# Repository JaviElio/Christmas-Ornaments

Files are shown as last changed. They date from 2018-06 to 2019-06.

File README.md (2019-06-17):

View this project on [CADLAB.io](https://cadlab.io/project/1880). 

# Christmas-Ornaments
ESP8266 Christmas ornaments 

Based on this project:

	- Title:	ESP8266 Christmas Ornaments!
	- Author:	Sean Hodgins
	- Link:		https://www.instructables.com/id/ESP8266-Christmas-Ornaments/

FEATURES:

If front button of the ornament is pressed, a random song is played. Then, other ornaments plays a song too (within 5 min max.)

Every time the front button is pressed a counter in thinkSpesk.com is increased. Also, every 5 min. the counter is checked to know if a song must be played.

If the ornament could not reach a wifi AP, a captative portal is activated to configure a connection to different Wifi AP.

PICTURES:

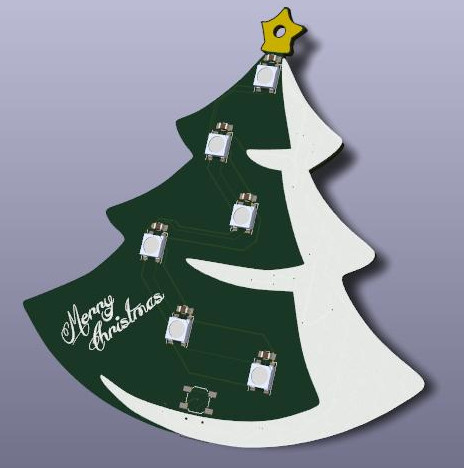
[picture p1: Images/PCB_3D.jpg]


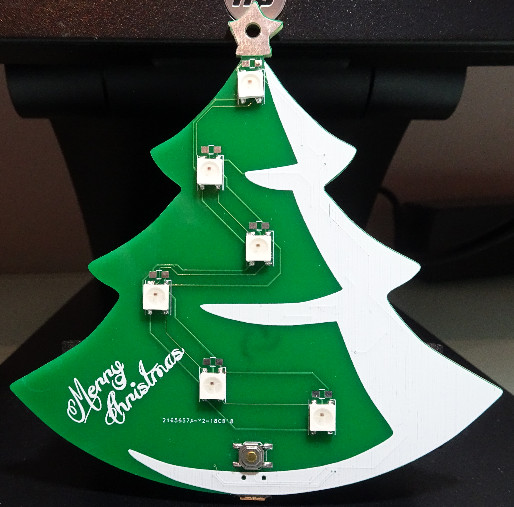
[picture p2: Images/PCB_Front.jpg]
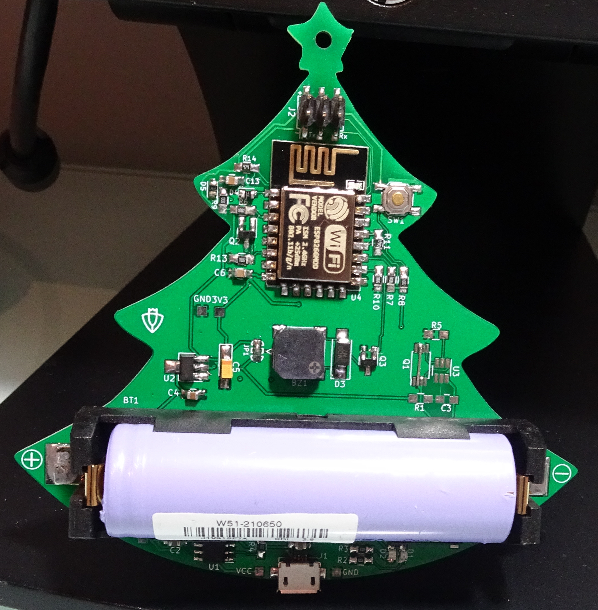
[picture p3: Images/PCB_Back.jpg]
		

TO IMPROVE:

Voltage regulator doesn't work if battery protection circuit is populated.

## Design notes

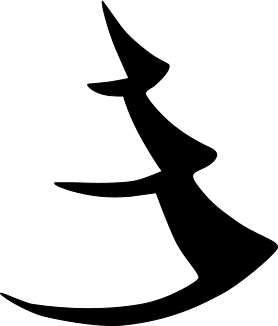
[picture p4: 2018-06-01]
Images/Tree_Shadow.png

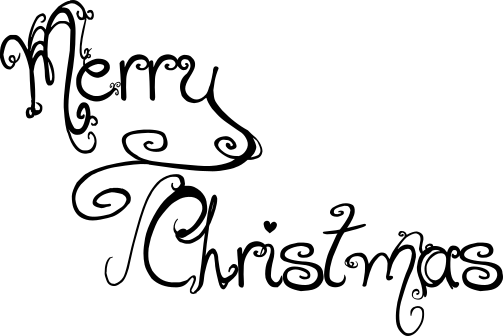
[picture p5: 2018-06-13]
Images/Text2.png

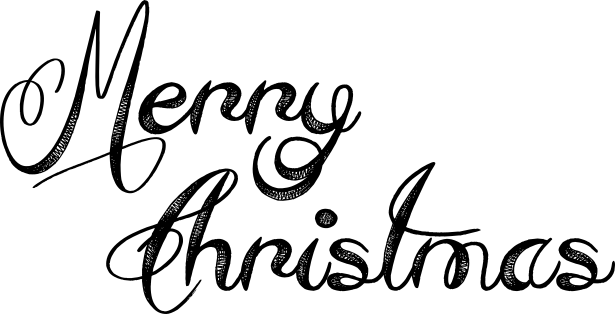
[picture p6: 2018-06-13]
Images/Text.png

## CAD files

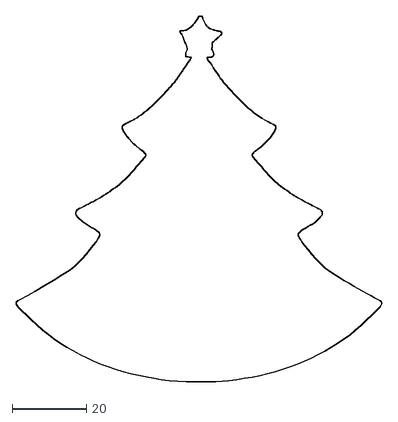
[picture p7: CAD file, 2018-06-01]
Images/Tree.dxf
98.8 x 98.7

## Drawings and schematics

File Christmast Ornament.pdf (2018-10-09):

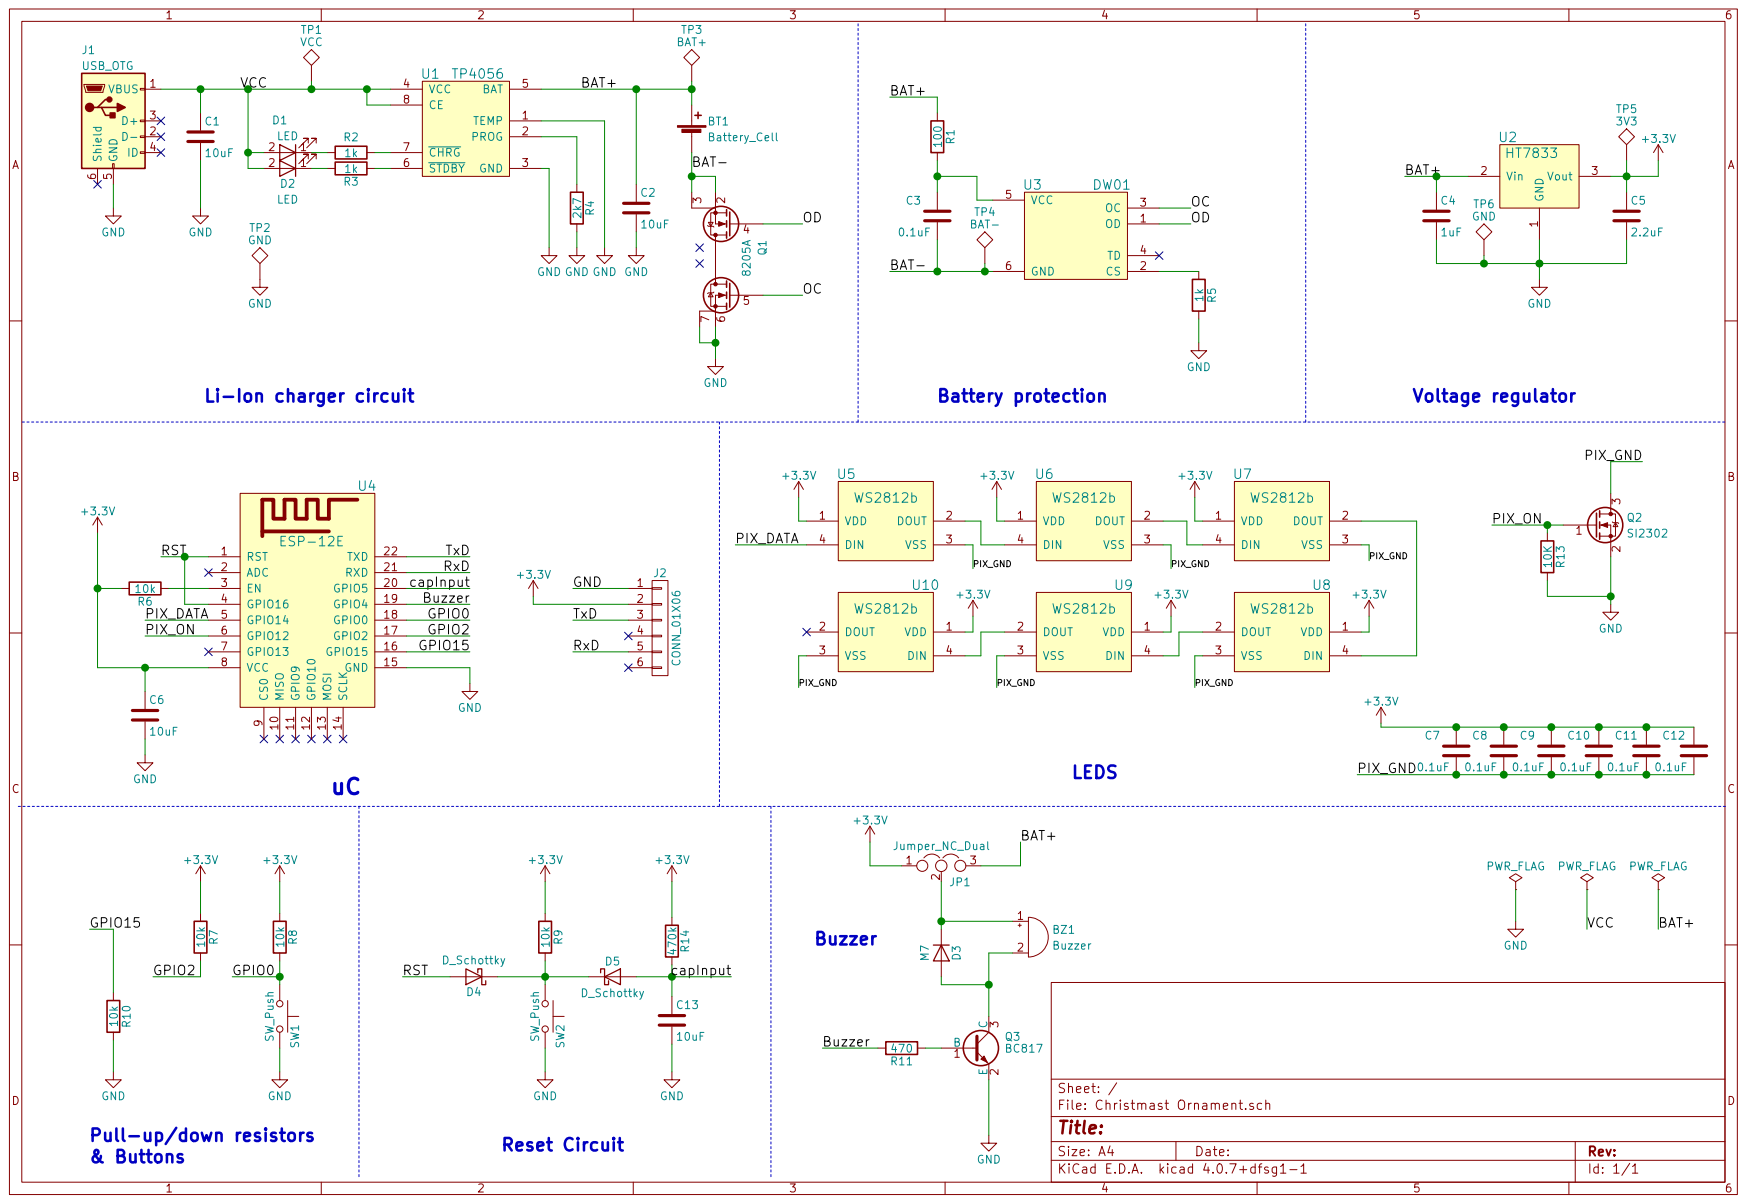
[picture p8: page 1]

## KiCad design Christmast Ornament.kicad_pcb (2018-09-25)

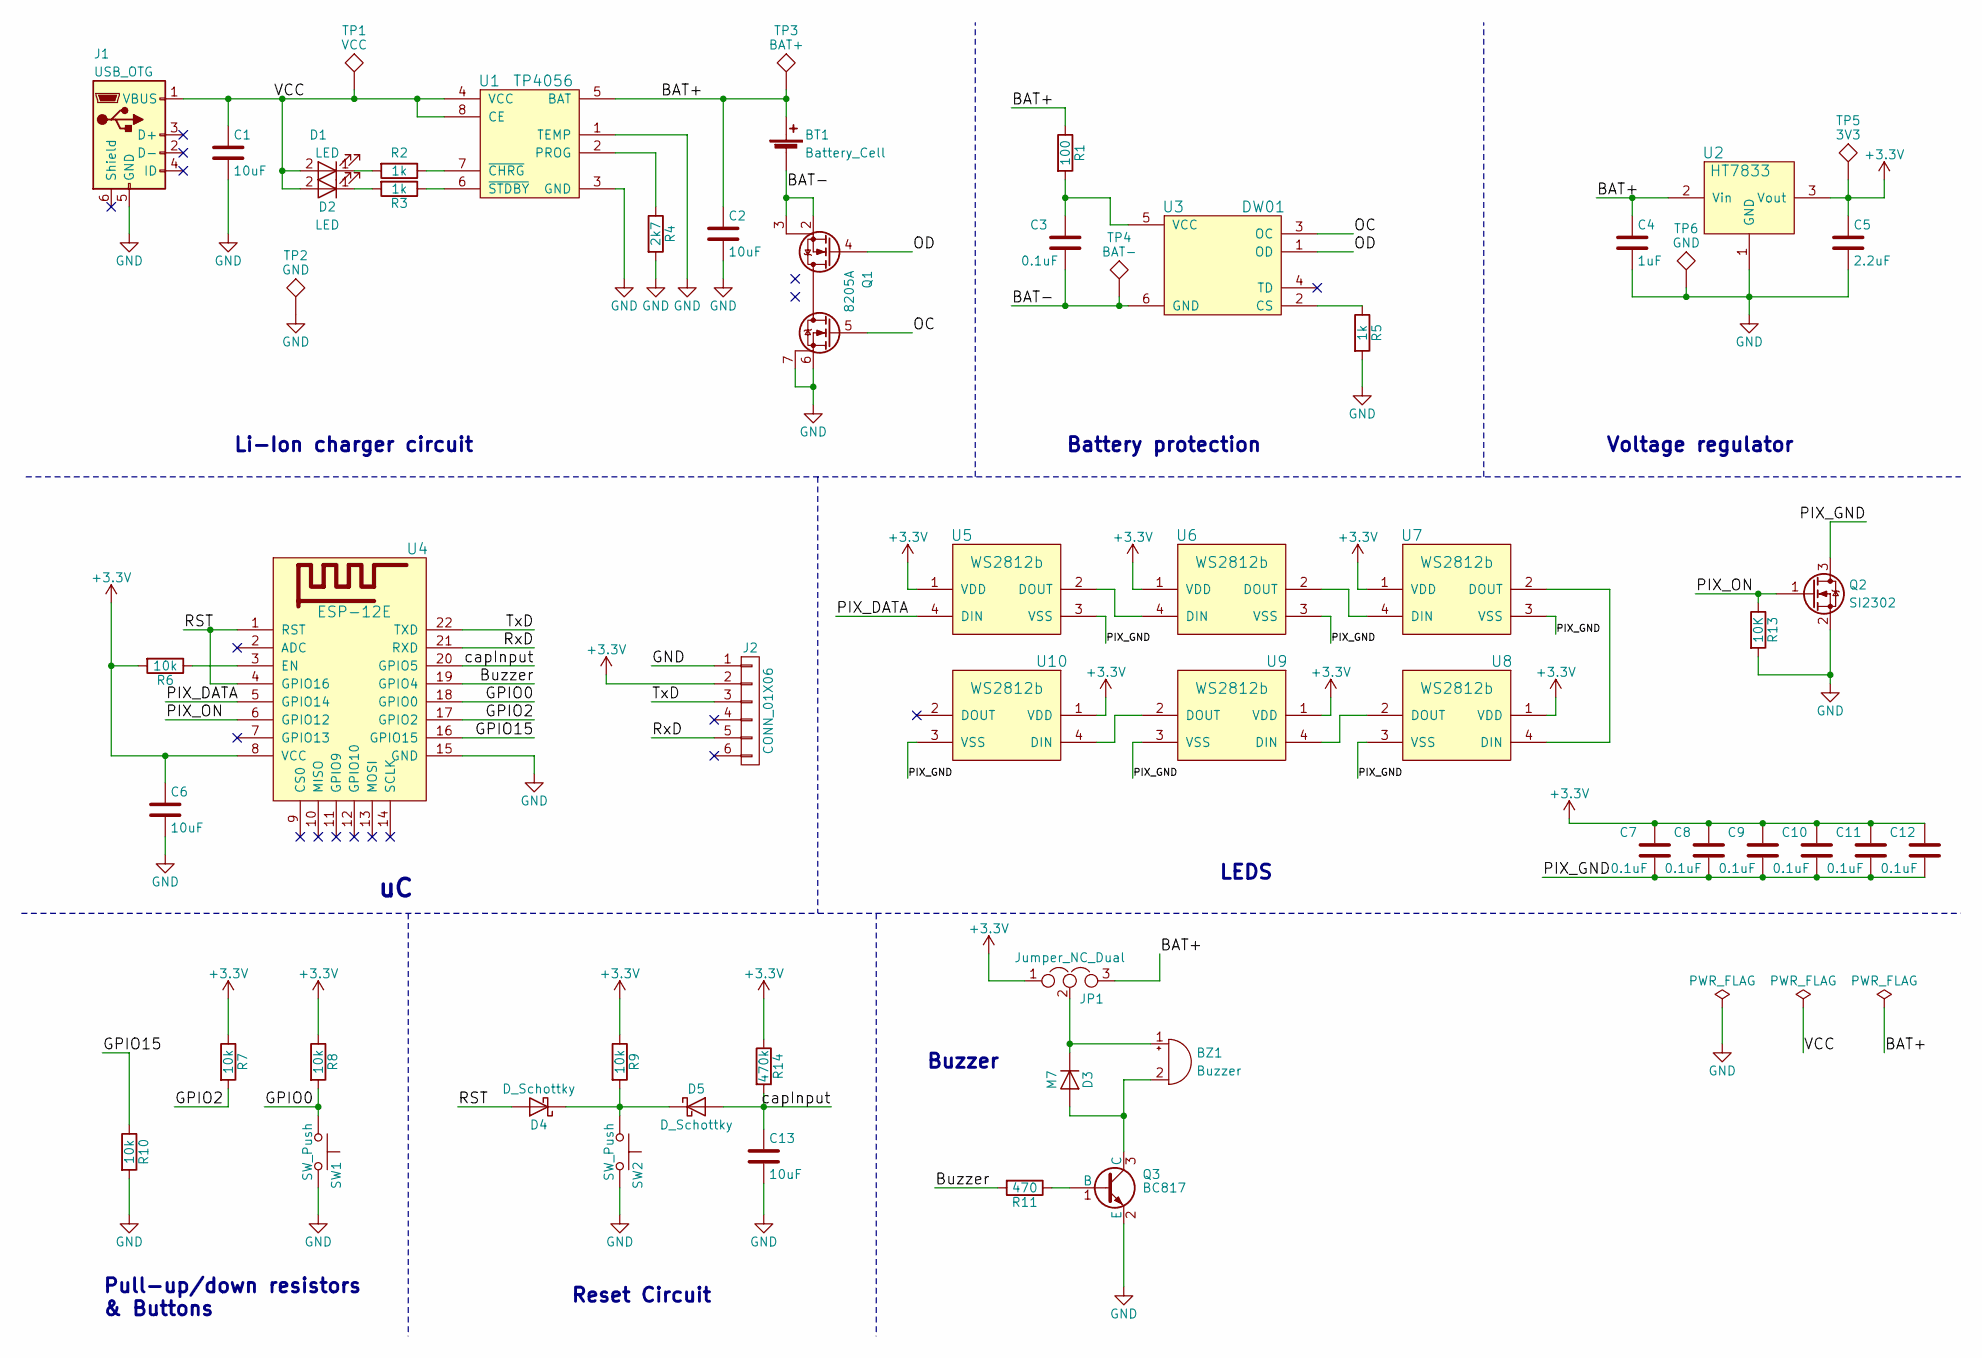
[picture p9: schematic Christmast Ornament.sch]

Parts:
BT1: Battery_Cell; 18650_SMD_Case
BZ1: Buzzer; Buzzer_8.5x8.5mm
C1, C2, C6, C13: 10uF; C_0805_HandSoldering
C3, C7, C8, C9, C10, C11, C12: 0.1uF; C_0805_HandSoldering
C4: 1uF; C_0805_HandSoldering
C5: 2.2uF; CP_Tantalum_Case-A_EIA-3216-18_Hand
D1, D2: LED; LED_0805
D3: M7; D_SMA_Handsoldering
D4, D5: D_Schottky; D_0805
J1: USB_OTG; MicroUSB
J2: CONN_01X06; Pin_Header_Straight_2x03_Pitch2.54mm_SMD
JP1: Jumper_NC_Dual; Jumper_2-NC
Q1: 8205A; TSSOP-8_4.4x3mm_Pitch0.65mm
Q2: SI2302; SOT-23_Handsoldering
Q3: BC817; SOT-23_Handsoldering
R1: 100; R_0805_HandSoldering
R2, R3, R5: 1k; R_0805_HandSoldering
R4: 2k7; R_0805_HandSoldering
R6, R7, R8, R9, R10: 10k; R_0805_HandSoldering
R11: 470; R_0805_HandSoldering
R13: 10K; R_0805_HandSoldering
R14: 470k; R_0805_HandSoldering
SW1, SW2: SW_Push; SW_SPST_SKQG
TP1: VCC; Measurement_Point_Square-SMD-Pad_Small
TP2, TP6: GND; Measurement_Point_Square-SMD-Pad_Small
TP3: BAT+; Measurement_Point_Square-SMD-Pad_Small
TP4: BAT-; Measurement_Point_Square-SMD-Pad_Small
TP5: 3V3; Measurement_Point_Square-SMD-Pad_Small
U1: TP4056; SOIC-8_3.9x4.9mm_Pitch1.27mm
U2: HT7833; SOT89-3_Housing_Handsoldering
U3: DW01; SOT-23-6_Handsoldering
U4: ESP-12E; ESP-12E_SMD
U5, U6, U7, U8, U9, U10: WS2812b; LED_WS2812B-PLCC4

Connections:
+3V3: C5.1, C6.1, C7.1, C8.1, C9.1, C10.1, C11.1, C12.1, J2.2, JP1.1, R6.2, R7.1, R8.1, R9.1, R14.1, TP5.1, U2.3 (Vout), U4.8 (VCC), U5.1 (VDD), U6.1 (VDD), U7.1 (VDD), U8.1 (VDD), U9.1 (VDD), U10.1 (VDD)
/BAT+: BT1.1 (+), C2.1, C4.1, JP1.3, R1.1, TP3.1, U1.5 (BAT), U2.2 (Vin)
/BAT-: BT1.2 (-), C3.2, Q1.2 (S1), Q1.3 (S1), TP4.1, U3.6 (GND)
/Buzzer: R11.2, U4.19 (GPIO4)
/GPIO0: R8.2, SW1.1, U4.18 (GPIO0)
/GPIO2: R7.2, U4.17 (GPIO2)
/GPIO15: R10.1, U4.16 (GPIO15)
/OC: Q1.5 (G2), U3.3 (OC)
/OD: Q1.4 (G1), U3.1 (OD)
/PIX_DATA: U4.5 (GPIO14), U5.4 (DIN)
/PIX_GND: C7.2, C8.2, C9.2, C10.2, C11.2, C12.2, Q2.3 (D), U5.3 (VSS), U6.3 (VSS), U7.3 (VSS), U8.3 (VSS), U9.3 (VSS), U10.3 (VSS)
/PIX_ON: Q2.1 (G), R13.1, U4.6 (GPIO12)
/RST: D4.2 (A), U4.1 (RST), U4.4 (GPIO16)
/RxD: J2.5, U4.21 (RXD)
/TxD: J2.3, U4.22 (TXD)
/VCC: C1.1, D1.2 (A), D2.2 (A), J1.1 (VBUS), TP1.1, U1.4 (VCC), U1.8 (CE)
/capInput: C13.1, D5.2 (A), R14.2, U4.20 (GPIO5)
GND: C1.2, C2.2, C4.2, C5.2, C6.2, C13.2, J1.5 (GND), J2.1, Q1.6 (S2), Q1.7 (S2), Q2.2 (S), Q3.2 (E), R4.2, R5.2, R10.2, R13.2, SW1.2, SW2.2, TP2.1, TP6.1, U1.1 (TEMP), U1.3 (GND), U2.1 (GND), U4.15 (GND)
unnamed: BZ1.1 (-), D3.1 (K), JP1.2
unnamed: BZ1.2 (+), D3.2 (A), Q3.3 (C)
unnamed: C3.1, R1.2, U3.5 (VCC)
unnamed: D1.1 (K), R2.2
unnamed: D2.1 (K), R3.2
unnamed: D4.1 (K), D5.1 (K), R9.2, SW2.1
unnamed: Q3.1 (B), R11.1
unnamed: R2.1, U1.7 (~CHRG)
unnamed: R3.1, U1.6 (~STDBY)
unnamed: R4.1, U1.2 (PROG)
unnamed: R5.1, U3.2 (CS)
unnamed: R6.1, U4.3 (EN)
unnamed: U5.2 (DOUT), U6.4 (DIN)
unnamed: U6.2 (DOUT), U7.4 (DIN)
unnamed: U7.2 (DOUT), U8.4 (DIN)
unnamed: U8.2 (DOUT), U9.4 (DIN)
unnamed: U9.2 (DOUT), U10.4 (DIN)

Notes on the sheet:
Li-Ion charger circuit
Battery protection
Voltage regulator
LEDS
Buzzer
Pull-up/down resistors & Buttons
Reset Circuit

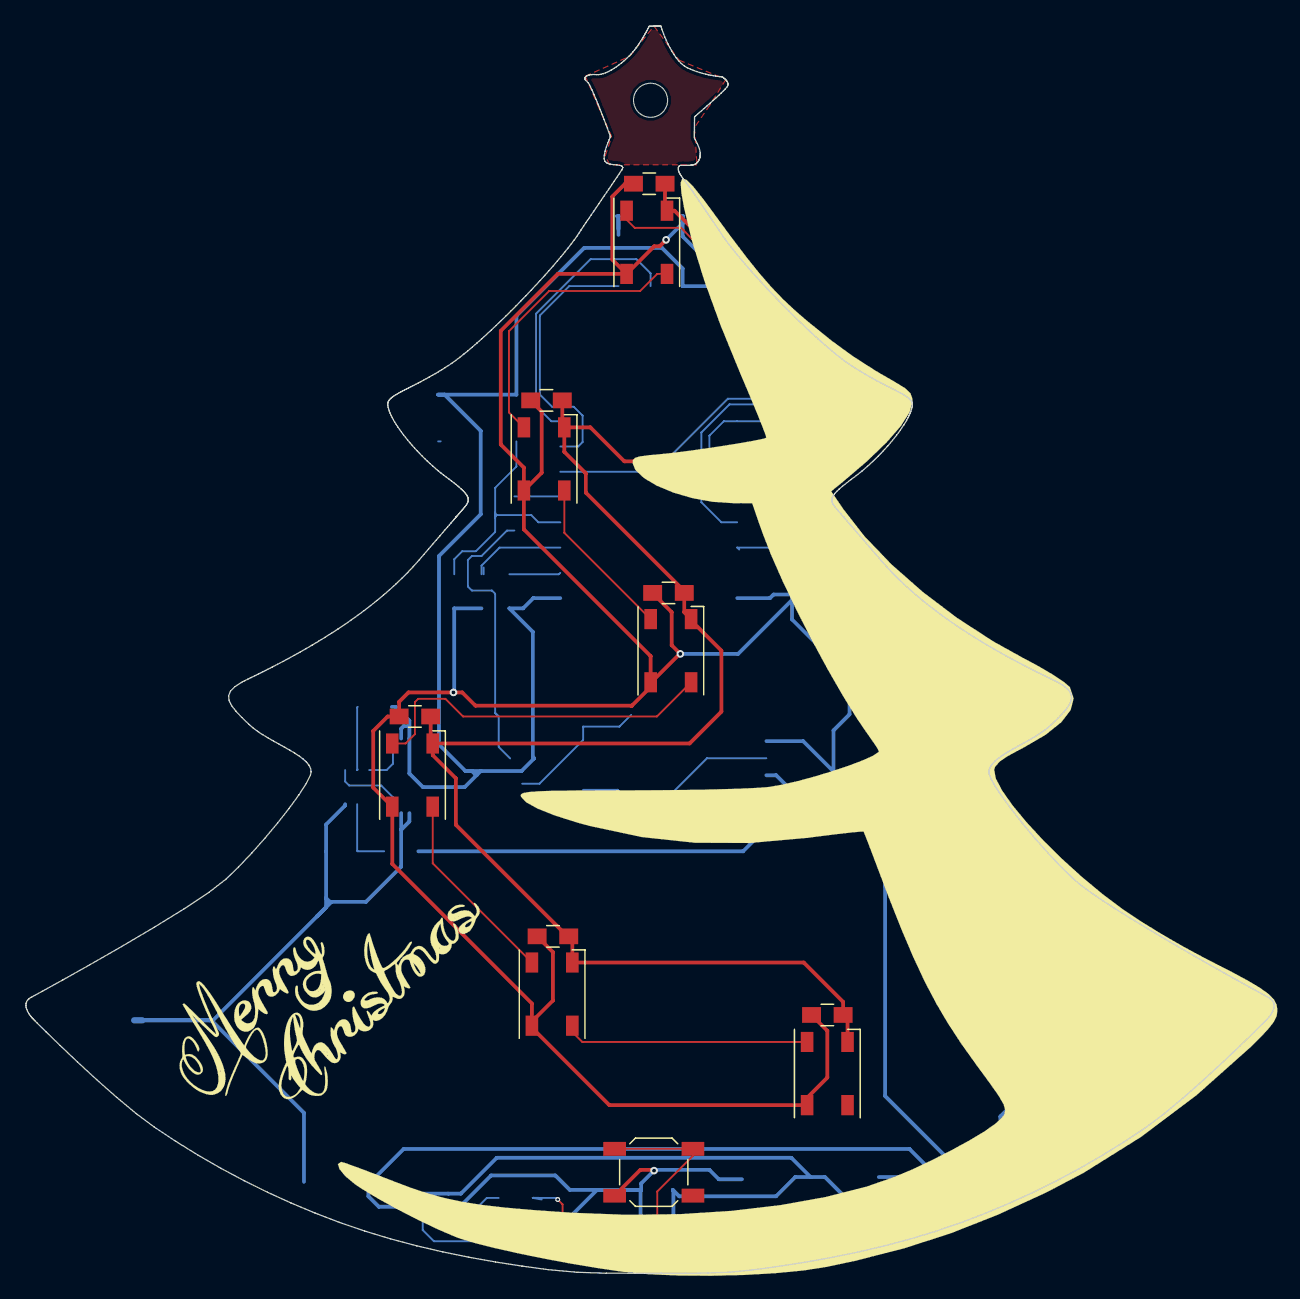
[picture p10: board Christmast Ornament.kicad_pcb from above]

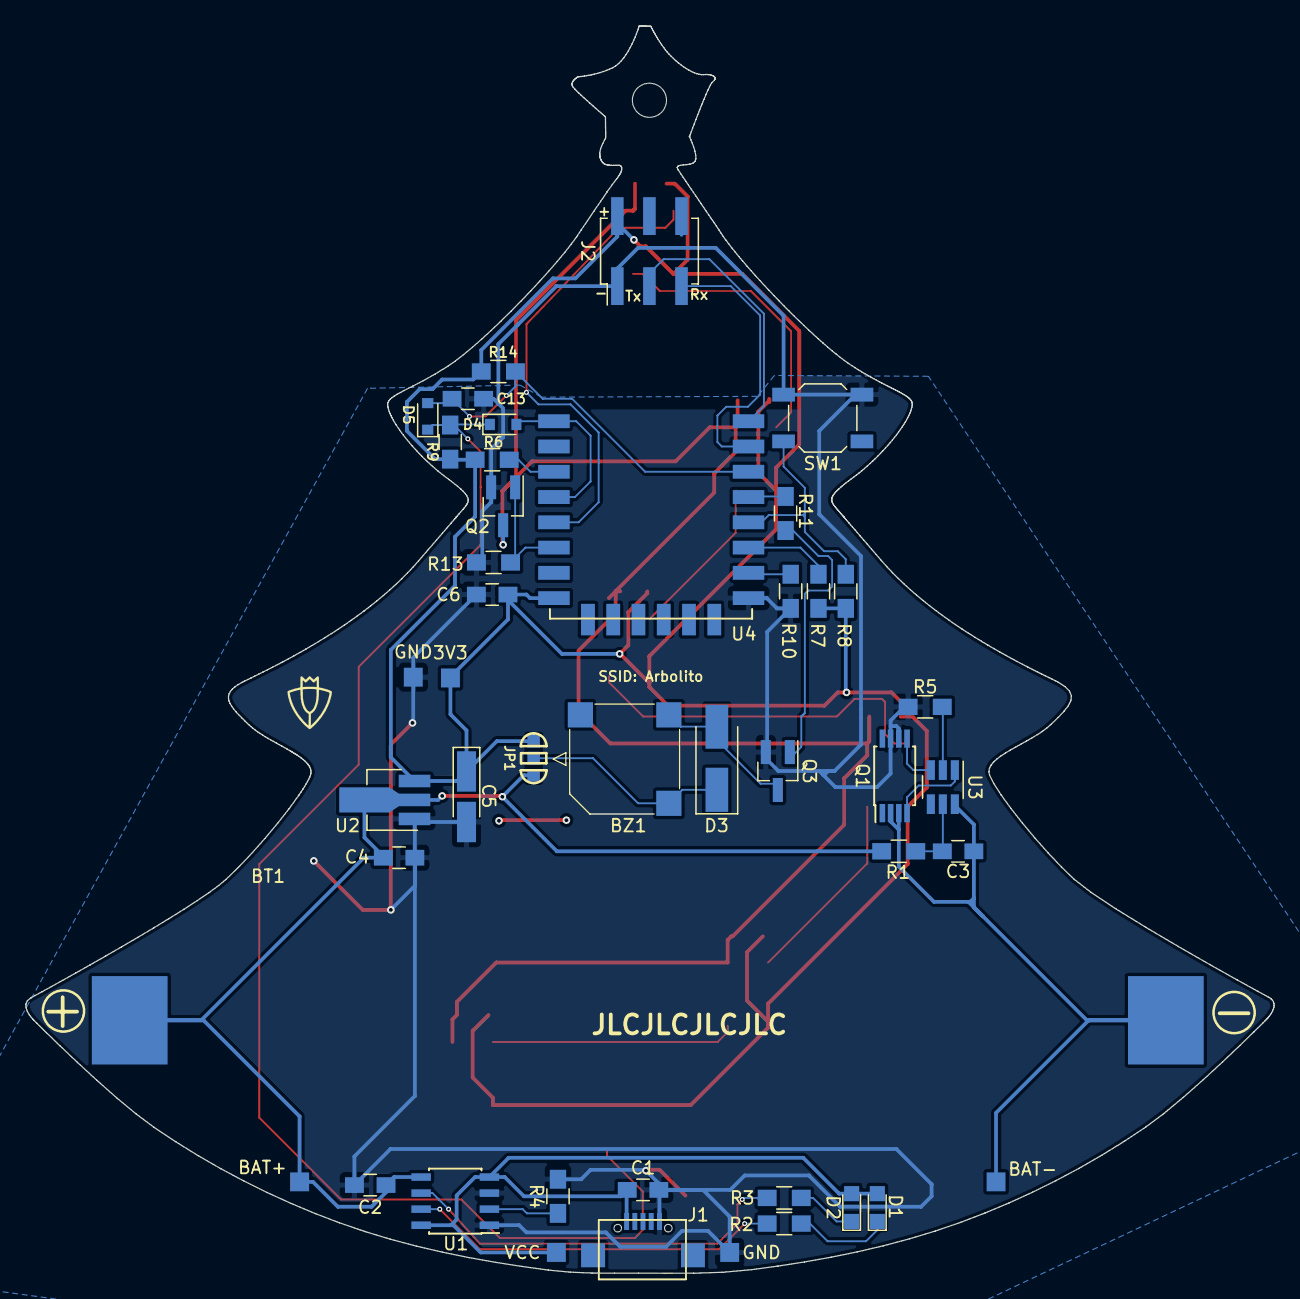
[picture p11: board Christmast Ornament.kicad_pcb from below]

Board: 2 copper layers, 98.8 x 98.7 mm, 57 parts (44 on the bottom side), 35 nets.

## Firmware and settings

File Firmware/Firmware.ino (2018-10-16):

#include <Adafruit_NeoPixel.h>
#include <ESP8266WiFi.h>
#include <DNSServer.h>
#include <ESP8266WebServer.h>
#include <WiFiManager.h>
#include <ThingSpeak.h>
#include <EEPROM.h>
#include <Ticker.h>


#define B3 2024
#define C4 1915
#define D4 1700
#define E4 1519
#define F4 1432
#define FS4 1352
#define G4 1275
#define GS4 415
#define A4 1136
#define AS4 1073
#define B4 1014
#define C5 956
#define D5 852

#define PIXELNUM 6
#define PIXELPIN 14
#define PIXELON  12
#define TONEPIN  4
#define CAPINPUT 5

#define SLEEPMINUTES 5


int song = 1;
bool mute = 0;
int rstReason;
bool capInputState = true;
unsigned long contadorChannel = 399088;
const char* writeContadorKey = "9SNXBSDH9JRAYYMD";
const char* readContadorKey = "ZCJM5M59A17ORGOO";

uint8_t cheers;
uint8_t savedCheers;

/*******************************************************
   Songs
 ********************************************************/

int tempo = 100;

int  Frostylength = 31;
int  Frostynotes[] = {G4, E4, F4, G4, C5, B4, C5, D5, C5, B4, A4, G4, 0, B4, C5, D5, C5, B4, A4, A4, G4, C5, E4, G4, A4, G4, F4, E4, D4, C4, 0};
int  Frostybeats[] = {4, 4, 1, 2, 4, 1, 1, 2, 2, 2, 2, 4, 2, 1, 1, 2, 2, 2, 1, 1, 2, 2, 2, 1, 1, 2, 2, 2, 2, 4, 1};

int  Merrylength = 31;
int  Merrynotes[] = {D4, G4, G4, A4, G4, FS4, E4, E4, E4, A4, A4, B4, A4, G4, FS4, D4, D4, B4, B4, C5, B4, A4, G4, E4, D4, D4, E4, A4, FS4, G4, 0};
int  Merrybeats[] = {2, 2, 1, 1, 1, 1, 2, 2, 2, 2, 1, 1, 1, 1, 2, 2, 2, 2, 1, 1, 1, 1, 2, 2, 1, 1, 2, 2, 2, 4, 1};

int  Jinglelength = 27;
int  Jinglenotes[] = {B4, B4, B4, B4, B4, B4, B4, D5, G4, A4, B4, 0, C5, C5, C5, C5, C5, B4, B4, B4, B4, A4, A4, B4, A4, D5, 0};
int  Jinglebeats[] = {2, 2, 4, 2, 2, 4, 2, 2, 2, 2, 4, 4, 2, 2, 2, 2, 2, 2, 2, 2, 2, 2, 2, 2, 4, 4, 1};

int Decklength = 18;
int Decknotes[] = {G4, F4, E4, D4, C4, D4, E4, C4, D4, E4, F4, D4, E4, D4, C4, B3, C4, 0};
int Deckbeats[] = {4, 1, 2, 2, 2, 2, 2, 2, 1, 1, 1, 1, 4, 1, 2, 2, 4, 1};


Adafruit_NeoPixel pixels = Adafruit_NeoPixel( PIXELNUM, PIXELPIN);
WiFiManager wifimanager;
WiFiClient client;
Ticker ticker;


void setup() {

  // Config capInput and save value
  pinMode(CAPINPUT, INPUT);
  capInputState = digitalRead(CAPINPUT);

  pinMode(PIXELON, OUTPUT);
  pinMode(PIXELPIN, OUTPUT);
  pinMode(LED_BUILTIN, OUTPUT);
  digitalWrite(PIXELON, LOW);
  digitalWrite(PIXELPIN, HIGH);
  digitalWrite(LED_BUILTIN, HIGH);
  

  pinMode(LED_BUILTIN, OUTPUT);
  digitalWrite(LED_BUILTIN, HIGH);

  Serial.begin(115200);
  Serial.println();
  pixels.begin();
  EEPROM.begin(4);

  if (mute == false) pinMode(TONEPIN, OUTPUT);


  ///////////////////////
  // CHECK RESET REASON
  ///////////////////////
  rst_info *rsti;
  rsti = ESP.getResetInfoPtr();
  rstReason = rsti->reason;
  Serial.println();
  Serial.print("ESP.getResetReason = ");
  Serial.println(ESP.getResetReason());
  Serial.println(String("ResetInfo.reason = ") + rstReason);
  //////////////////////////


}

void loop() {


  Serial.print("CapInput= ");
  Serial.println(capInputState, BIN);

  if (capInputState == true) {


    // 1.Check current "cheers"
    // 2.Play Music if required
    // 3.Save new "cheers" number
    // 4.Sleep

    wifimanager.autoConnect("Arbolito");
    Serial.println();
    Serial.println("Conectado!!");
    ticker.detach();
    digitalWrite(LED_BUILTIN, HIGH);
    digitalWrite(PIXELON, LOW);
    digitalWrite(PIXELPIN, HIGH);

    ThingSpeak.begin(client, "api.thingspeak.com", 80);
    cheers = ThingSpeak.readIntField(contadorChannel, 1, readContadorKey);
    Serial.print("Current Cheers: ");
    Serial.println(cheers);

    savedCheers = EEPROM.read(0);
    Serial.print("Saved Cheers: ");
    Serial.println(savedCheers);


    if (cheers != savedCheers && cheers != 0) {

      PlaySong();
      EEPROM.write(0, cheers);
      EEPROM.commit();

    }


    Serial.print("Sleep ");
    Serial.print(SLEEPMINUTES);
    Serial.println(" minutes");
    ESP.deepSleep(SLEEPMINUTES * 60 * 1000 * 1000);

  }
  else {


    // 1.Play Music
    // 2.Check current "cheers" and increase 1
    // 3.Save new "cheers" number
    // 4.Sleep

    PlaySong();

    wifimanager.setAPCallback(configModeCallback);
    wifimanager.autoConnect("Arbolito");
    Serial.println();
    Serial.println("Conectado!!");
    ticker.detach();
    digitalWrite(LED_BUILTIN, HIGH);
    digitalWrite(PIXELON, LOW);
    digitalWrite(PIXELPIN, HIGH);


    ThingSpeak.begin(client, "api.thingspeak.com", 80);
    cheers = ThingSpeak.readIntField(contadorChannel, 1, readContadorKey);
    Serial.print("Current Cheers: ");
    Serial.println(cheers);

    ThingSpeak.writeField(contadorChannel, 1, cheers + 1, writeContadorKey);
    Serial.print("New Cheers: ");
    Serial.println(cheers + 1);

    EEPROM.write(0, cheers + 1);
    EEPROM.commit();


    Serial.print("Sleep ");
    Serial.print(SLEEPMINUTES);
    Serial.println(" minutes");
    ESP.deepSleep(SLEEPMINUTES * 60 * 1000 * 1000);

  }

}



void showRandomColors(int numPixel) {

  int pixelColor[numPixel][3];

  //Fill Array of colors
  for (int i = 0; i < numPixel; i++) {
    for (int j = 0; j < 3; j++) {
      pixelColor[i][j] = random(0, 51);
    }

    pixels.setPixelColor(i, pixels.Color(pixelColor[i][0], pixelColor[i][1], pixelColor[i][2])); // Set random colors

  }

  pixels.show();

}


void PlaySong() {
  song = random(1, 5);

  Serial.print("Play song ");
  Serial.println(song);
  digitalWrite(PIXELON, HIGH);

  switch (song) {
    case 1:
      Serial.println("Frosty");
      Frosty();
      break;
    case 2:
      Serial.println("Merry");
      Merry();
      break;
    case 3:
      Serial.println("Deck");
      Deck();
      break;
    case 4:
      Serial.println("Jingle");
      Jingle();
      break;
  }


  digitalWrite(PIXELON, LOW);
  digitalWrite(PIXELPIN, HIGH);
  Serial.println("End Song");

}


void Frosty() {
  for (int i = 0; i < Frostylength; i++) {
    if (Frostynotes[i] == 0) {
      delay(Frostybeats[i] * tempo); // rest
      noTone(TONEPIN);
    } else {
      playNote(Frostynotes[i], Frostybeats[i] * tempo);
    }

    // pause between notes
    delay(tempo / 2);
    if (Frostynotes[i + 1] == Frostynotes[i]) {
      noTone(TONEPIN);
    }
  }
  noTone(TONEPIN);
}

void Merry() {
  for (int i = 0; i < Merrylength; i++) {
    if (Merrynotes[i] == 0) {
      delay(Merrybeats[i] * tempo); // rest
      noTone(TONEPIN);
    } else {
      playNote(Merrynotes[i], Merrybeats[i] * tempo);
    }

    // pause between notes
    delay(tempo / 2);
    if (Merrynotes[i + 1] == Merrynotes[i]) {
      noTone(TONEPIN);
    }
  }
  noTone(TONEPIN);
}

void Deck() {
  for (int i = 0; i < Decklength; i++) {
    if (Decknotes[i] == 0) {
      delay(Deckbeats[i] * tempo); // rest
      noTone(TONEPIN);
    } else {

      playNote(Decknotes[i], Deckbeats[i] * tempo);
    }

    // pause between notes
    delay(tempo / 2);
    if (Decknotes[i + 1] == Decknotes[i]) {
      noTone(TONEPIN);
    }
  }
  noTone(TONEPIN);
}

void Jingle() {
  for (int i = 0; i < Jinglelength; i++) {
    if (Jinglenotes[i] == 0) {
      delay(Jinglebeats[i] * tempo); // rest
      noTone(TONEPIN);
    } else {

      playNote(Jinglenotes[i], Jinglebeats[i] * tempo);
    }

    // pause between notes
    delay(tempo / 2);
    if (Jinglenotes[i + 1] == Jinglenotes[i]) {
      noTone(TONEPIN);
    }
  }
  noTone(TONEPIN);
}

void playNote(int note, int duration) {

  showRandomColors(PIXELNUM);
  playTone(note, duration);

}


void playTone(int tone, int duration) {
  for (long i = 0; i < duration * 1000L; i += tone * 2) {
    digitalWrite(TONEPIN, HIGH);
    delayMicroseconds(tone);
    digitalWrite(TONEPIN, LOW);
    delayMicroseconds(tone);
  }
}

void configModeCallback (WiFiManager *myWiFiManager) {
  Serial.println("Entered config mode");
  Serial.println(WiFi.softAPIP());
  //if you used auto generated SSID, print it
  Serial.println(myWiFiManager->getConfigPortalSSID());
  ticker.attach(1, tick);

}

void tick()
{
  //toggle state of LED_BUILTIN

  digitalWrite(LED_BUILTIN, !digitalRead(LED_BUILTIN));


}

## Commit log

2018-05-26 First upload
    [Arbol.dxf, Christmast Ornament.kicad_pcb, Christmast Ornament.sch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]
2018-05-26 Buzzer circuit and test points
    [Arbol.dxf, Christmast Ornament.sch]
2018-06-01 First attempt to distribute components
    [Christmast Ornament.kicad_pcb, Christmast Ornament.sch, Tree.dxf]
2018-06-08 PCB routed
    [Christmast Ornament.kicad_pcb, Christmast Ornament.sch]
2018-06-13 PCB designed and gerbers
    [Christmast Ornament-B.Cu.gbr, Christmast Ornament-B.Mask.gbr, Christmast Ornament-B.SilkS.gbr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]
2018-07-24 TP4056 ground connection fixed
    [Christmast Ornament-B.Cu.gbr, Christmast Ornament-B.Mask.gbr, Christmast Ornament-B.SilkS.gbr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]
2018-07-25 8205A footprint changed
    [Christmast Ornament.kicad_pcb, Christmast Ornament.sch]
2018-08-15 Components added to reset button
    [Christmast Ornament.kicad_pcb, Christmast Ornament.sch]
2018-08-15 capInput routed and R12 deleted
    [Christmast Ornament.kicad_pcb, Christmast Ornament.sch]
2018-08-17 Gerber files generated
    [Christmast Ornament-B.Cu.gbr, Christmast Ornament-B.Mask.gbr, Christmast Ornament-B.SilkS.gbr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]
2018-08-20 SSID and password added to back silkscreen
    [Christmast Ornament-B.Cu.gbr, Christmast Ornament-B.Mask.gbr, Christmast Ornament-B.SilkS.gbr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]
2018-08-25 Status led indicatis if config portal is active
2018-08-25 Silkscreen text changed
    [Christmast Ornament.kicad_pcb]
2018-09-25 Added text for the custemer Id
    [Christmast Ornament-B.Cu.gbr, Christmast Ornament-B.Mask.gbr, Christmast Ornament-B.SilkS.gbr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]
2018-10-09 Schematic pdf uploaded
2018-10-16 Built in led blinks when captative portal is active
